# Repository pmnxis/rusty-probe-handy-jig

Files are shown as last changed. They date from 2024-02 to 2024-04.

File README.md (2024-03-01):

# The Rusty Probe

This is an open hardware probe for the Serial Wire Debug (SWD) and JTAG protocol.
Based on the RP2040 MCU.

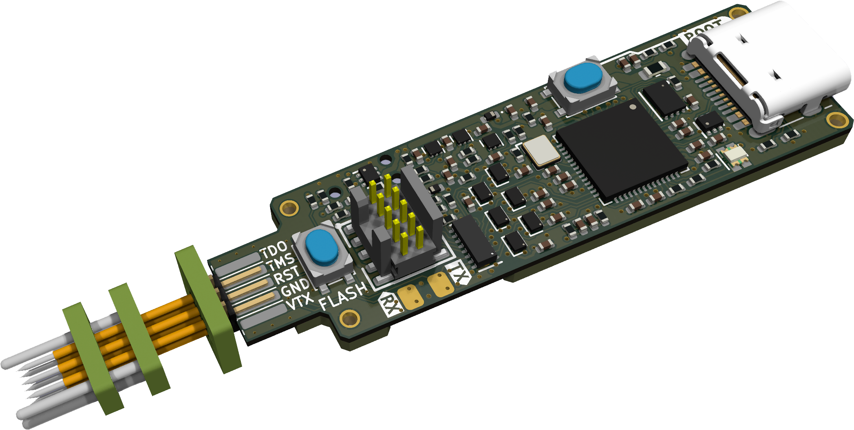
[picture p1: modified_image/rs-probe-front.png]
modified probe

Following image is forked and modified PCB 3D rendering.
This repo is modified PCB data details are descirbed in [here](#modification-on-this-forked-repo)

## Firmware

The firmware is available [here](https://github.com/probe-rs/rusty-probe-firmware) and is open-source.

## Features

- The 10-pin Cortex-Debug connector is used.
- The programming connector is the Tag Connect TC2030, however for just loading firmware the USB bootloader is recommended.
- Castellated vias for all programming pins, power and 2 GPIOs.
- USB-C connector.
- Target 5V and `Vtarget` is protected with an diode circuit to not have current flow from the target to the host.
- The probe support 1.8v - 3.3v signal voltage and can track `Vtarget`.
- The key pin on the Cortex-Debug can be connected to the protected 5V.

The schematic can be found in the GitHub actions, full production files are generated for each commit.

probe

## Comparison

Here is a small comparison with a few different probes:

| | Rusty Probe | PicoProbe | Raspberry Pi Debug Probe | STLinkV3 | JLink |
|---|---|---|---|---|---|
| Max speed | 62 MHz | ? | 10 MHz | 24 MHz | 15 MHz |
| Target support | any | any | any | STM32 | any |
| IO voltage control | 1.8-3.3V | 3.3V | 3.3V | 1.6-3.3V | 1.6-3.3V somtimes  |
| Type | Open Source & Hardware | Open Source | Proprietary | Proprietary | Proprietary |
| Language | Rust | C | C | C | C |
| Protocol | CMSIS-DAP | CMSIS-DAP | CMSIS-DAP | Proprietary | CMSIS-DAP |
| Programming connector | Cortex-M Debug 10p | - | JST | Cortex-M Debug 14p | Cortex-M Debug 10p |
| USB speed | 12 MBit/s | 12 MBit/s | 12 MBit/s | 480 MBit/s | 12 MBit/s |

## Where to buy

The original probe is available in the [probe-rs shop](https://shop.probe.rs/). But you are free to build one yourself as well!

## License

This work is licensed under [CERN-OHL-P](cern_ohl_p_v2.txt).

# Modification on this forked repo
modified probe
The existing rusty-probe has been modified for a practical experiment aiming to enable on-site, real-time firmware updates by individuals without programming knowledge. This modification incorporates BillMock-HW to facilitate firmware updates without the need for a computer.

## PCB Stack-Up
| | |
| --- | --- |
| Layer | 4 Layer |
| Material | FR4 |
| Impedence Control | Don't care (But choosed `JLC04081H-3313` ) |
| Thickness | **0.8 mm** |

In the modified board, a 1.27mm pin header is positioned at the left end to facilitate connection with a PogoProbe. The board is designed with a thickness of 0.8mm, considering the recommended thickness for the USB-C connector. While the original PCB uses 1.6mm thickness, using the USB-C connector directly (without PogoProbe) allows for the use of 1.6mm thickness as well.

By opting for the 0.8mm thickness, the durability of the PCB might be compromised. To address this, a BackPlane board is employed to reinforce and augment the insufficient rigidity.

| Front | Back |
| --- | --- |
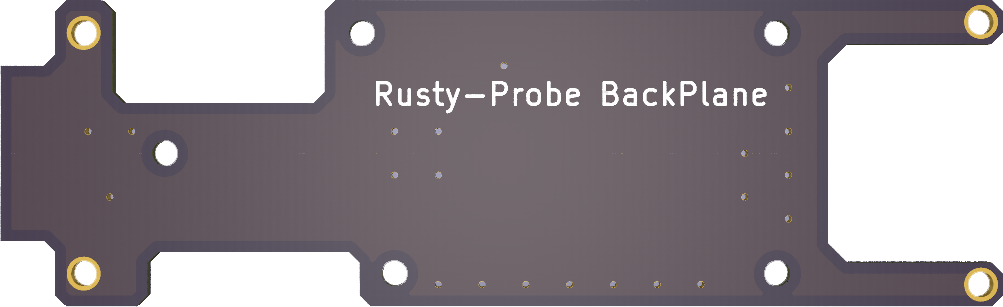
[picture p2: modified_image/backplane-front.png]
backplane-front
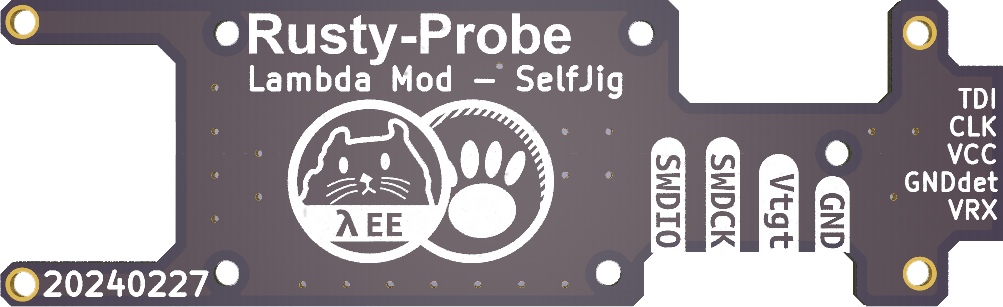
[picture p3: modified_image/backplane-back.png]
backplane-back
|  |  |
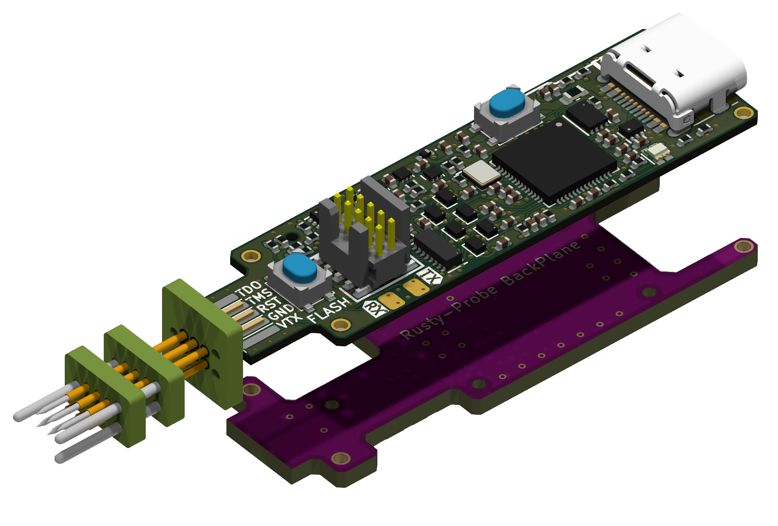
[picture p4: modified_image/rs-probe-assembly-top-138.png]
backplane-front-assembly-138mm
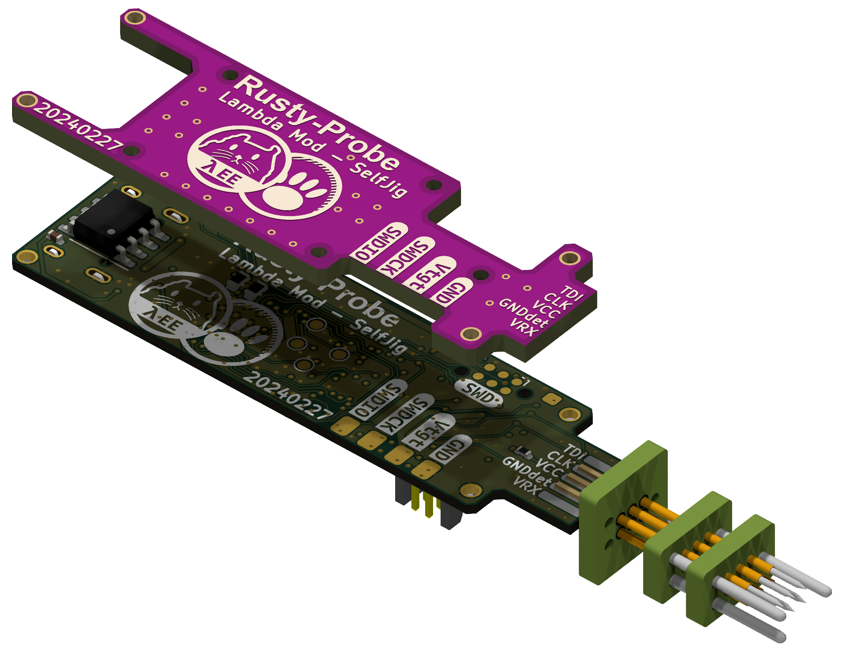
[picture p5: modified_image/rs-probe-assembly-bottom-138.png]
backplane-back-assembly-138mm
|  |  |
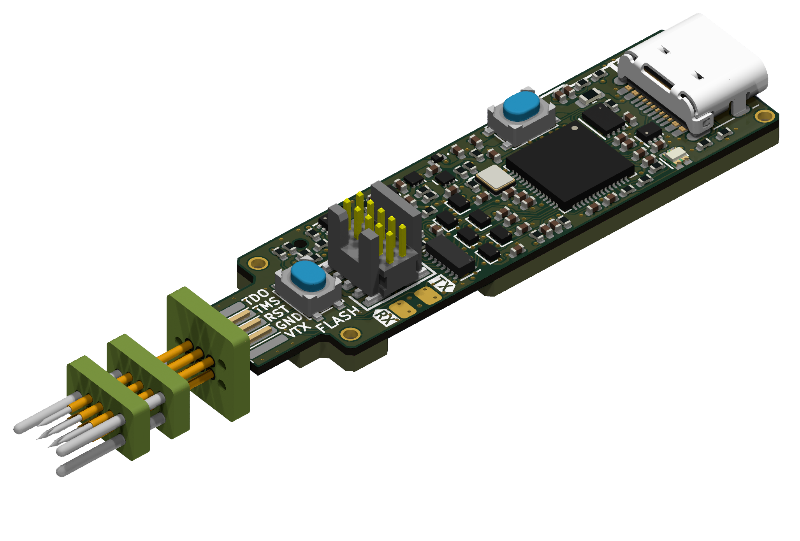
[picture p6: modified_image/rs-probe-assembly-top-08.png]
backplane-front-assembly-08mm
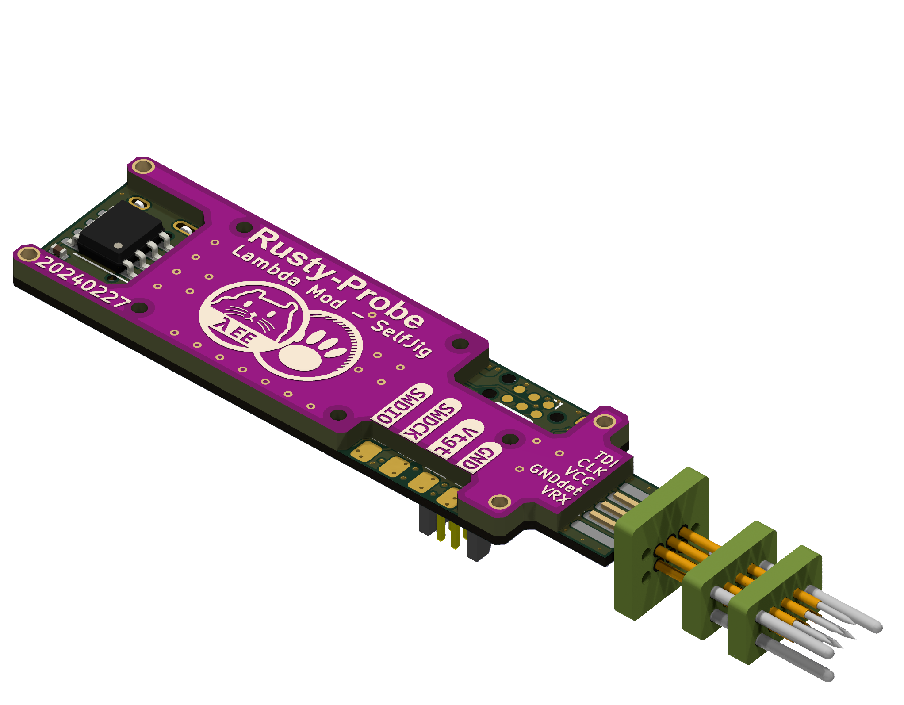
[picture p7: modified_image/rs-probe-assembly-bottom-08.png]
backplane-back-assembly-08mm
|  |  |
## Panelization 
JLCPCB's Panelization requires a minimum size of 70mm x 70mm when placing PCBs along the Edge Rail. To meet this requirement, I rotated the PCB by 90 degrees and arranged them in a 4x1 configuration. Additionally, I inserted a dummy bar in the middle for successful Panelization.

### Panlization by cli
```sh
# KiKit Required
cd ./panelize
./panelize_4batch.sh
```

## Changed Note
- Default `W25Q8` is replaced to `IS25WP016D` for custom code.
- Switch `EVQ-P2002W` is replaced to `TS-1145A-C-B` by personal ease of supply and demand of parts.
- Number of tact switch replaced to `TS-1145A-C-B` is changed to **2** from 1. Extra SW2 is connected to GPIO1. The plan of GPIO1 is using for USER input button (Ex Self Programming Button)
- Replace `74LVC1T45` to `X2-DFN1410-6` package and associated part.
- Castellated holes are removed for reducing the small scale unit production cost.
- The addition of a 5x2 SMD pad, designed to accommodate a 1.27mm pin header for vertical connection on the left side, has been made. This pad is intended for connecting a custom Pogo Pin (https://gitlab.com/michael1308/pogoprobe) and currently follows the pinout of the TC-2030 for consideration in the pin mapping of the personal project.
- Optionally added an I2C FRAM on the PCB bottom layer for data logging or frequent data storage purposes.
- Changed the selection of resistors and capacitors to those available in the JLCPCB Basic Part list.
- PCB width is increased to 49.9 mm from 40.0 mm
- Added and modified parameters to enable direct production with JLCPCB.
- Some libraries are referenced from [Lambda_KICAD_LIB](https://github.com/pmnxis/Lambda_KICAD_LIB)
kicad

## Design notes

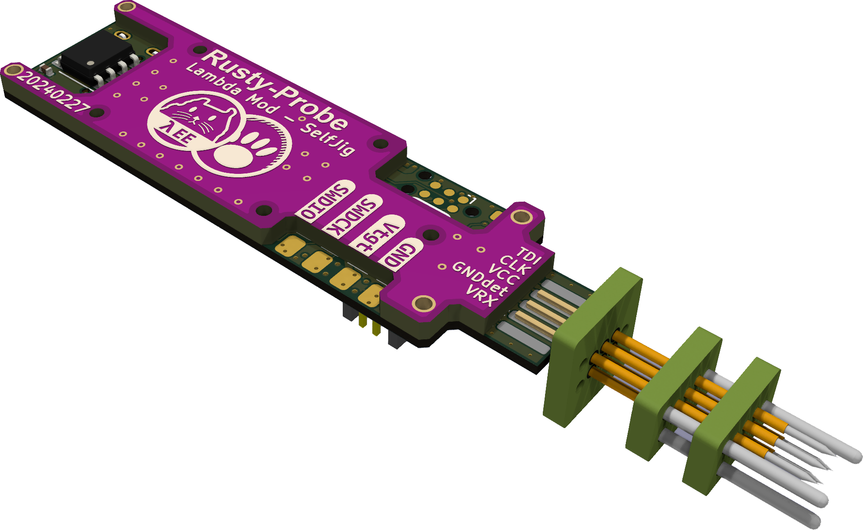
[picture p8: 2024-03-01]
modified_image/rs-probe-back.png

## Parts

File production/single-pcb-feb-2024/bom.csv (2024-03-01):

Designator | Footprint | Quantity | Value | LCSC Part #
C1, C10, C11, C12, C13, C14, C15, C16, C17, C18, C19, C20, C22, C23, C28, C31, C5, C7, C8, C9 | C_0402 | 20 | 0.1u | C307331
C2, C21, C24, C25, C26, C27, C29, C3, C30, C4, C6 | C_0402 | 11 | 2.2u | C170151
D1 | LED_LiteOn_LTST-C19HE1WT | 1 | LTST-C19HE1WT | C458749
D2, D3 | 0402 | 2 | 20V | C145312
F1 | 0603 | 1 | Fuse_Small | C210357
FB1 | R_0402 | 1 | BLM15AX601SN1D | C76886
J1 | USB_C_Receptacle_USB4105 | 1 | USB_C_Receptacle_USB2.0 | C167321
Q1 | SOT-563 | 1 | NTZD3155C | C895156
R1, R13, R15, R28 | R_0402 | 4 | 17.4k | C26957
R10, R18, R22, R23, R24, R26 | R_0402 | 6 | 1Meg | C138033
R11, R12, R14, R16, R19, R21, R27, R9 | R_0402 | 8 | 47k | C25792
R17, R2, R31, R5, R6, R7 | R_0402 | 6 | 1k | C11702
R20, R29, R3, R4, R8 | R_0402 | 5 | 5.1k | C25905
R25 | R_0402 | 1 | 15k | C25756
R30 | R_0402 | 1 | 0Ω | C17168
R32, R33 | R_0603 | 2 | 3.3kΩ 1608 | C22978
SW1, SW2 | SW_SPST_TS-1145A | 2 | TS-1145A-C-B | C465998
TH3, TH4 |  | 2 | Tooling Hole
U1, U10, U11, U2, U8, U9 | X2-DFN1410-6 | 6 | 74LVC1T45FZ4-7 | C150482
U12, U13, U14 | DFN-6-1EP_1.2x1.2mm_P0.4mm_EP0.3x0.94mm_PullBack | 3 | NCP133AMXADJTCG | C457672
U15 | SOIC-8_3.9x4.9mm_P1.27mm | 1 | FM24V02A-GTR | C382041
U3 | USON-8-3x2mm-EP | 1 | IS25WP016D-JULE-TR | C2976734
U4 | DFN-16-1EP_1.6x4mm_P0.5mm | 1 | NUF8401MNT4G | C895158
U5 | PinHeader_2x05_FTSH-105-01-L-DV-K | 1 | CortexDebug | C448647
U6 | RP2040-QFN-56 | 1 | RP2040 | C2040
U7 | SOT-563 | 1 | NUF2042XV6T1G | C90707
X1 | Crystal_SMD_2520-4Pin_2.5x2.0mm | 1 | 12 MHz | C255991

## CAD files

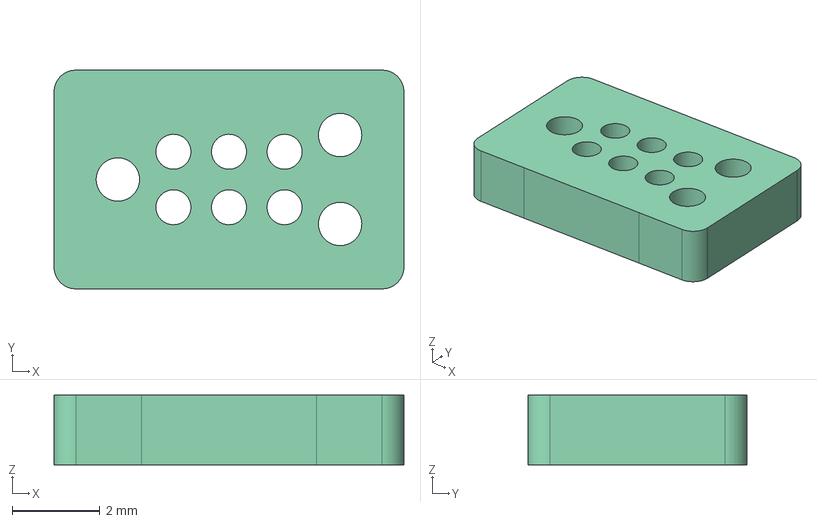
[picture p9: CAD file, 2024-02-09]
custom/TC2030-support.step
8.00 x 5.00 x 1.60 mm
Pcb_f6bc
topPads_f6bc
botPads_f6bc

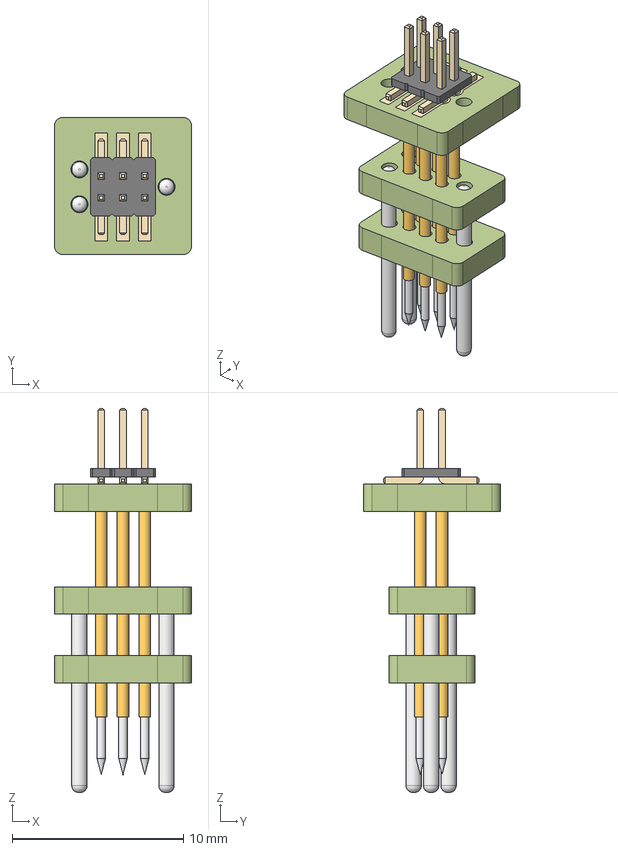
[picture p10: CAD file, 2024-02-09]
custom/PogoProbe-2030.step
8.00 x 8.00 x 22.4 mm
Pcb_ff3a
topPads_ff3a_cut
botPads_ff3a
REF_PinHeader_2x03_P127mm_Vertical_SMD_4153acf04981
REF_P50-E1_4153acf04981[2] x 6
REF_Body_0623b5cc9bbc x 3
REF_TC2030-support_e4265beada1b x 2

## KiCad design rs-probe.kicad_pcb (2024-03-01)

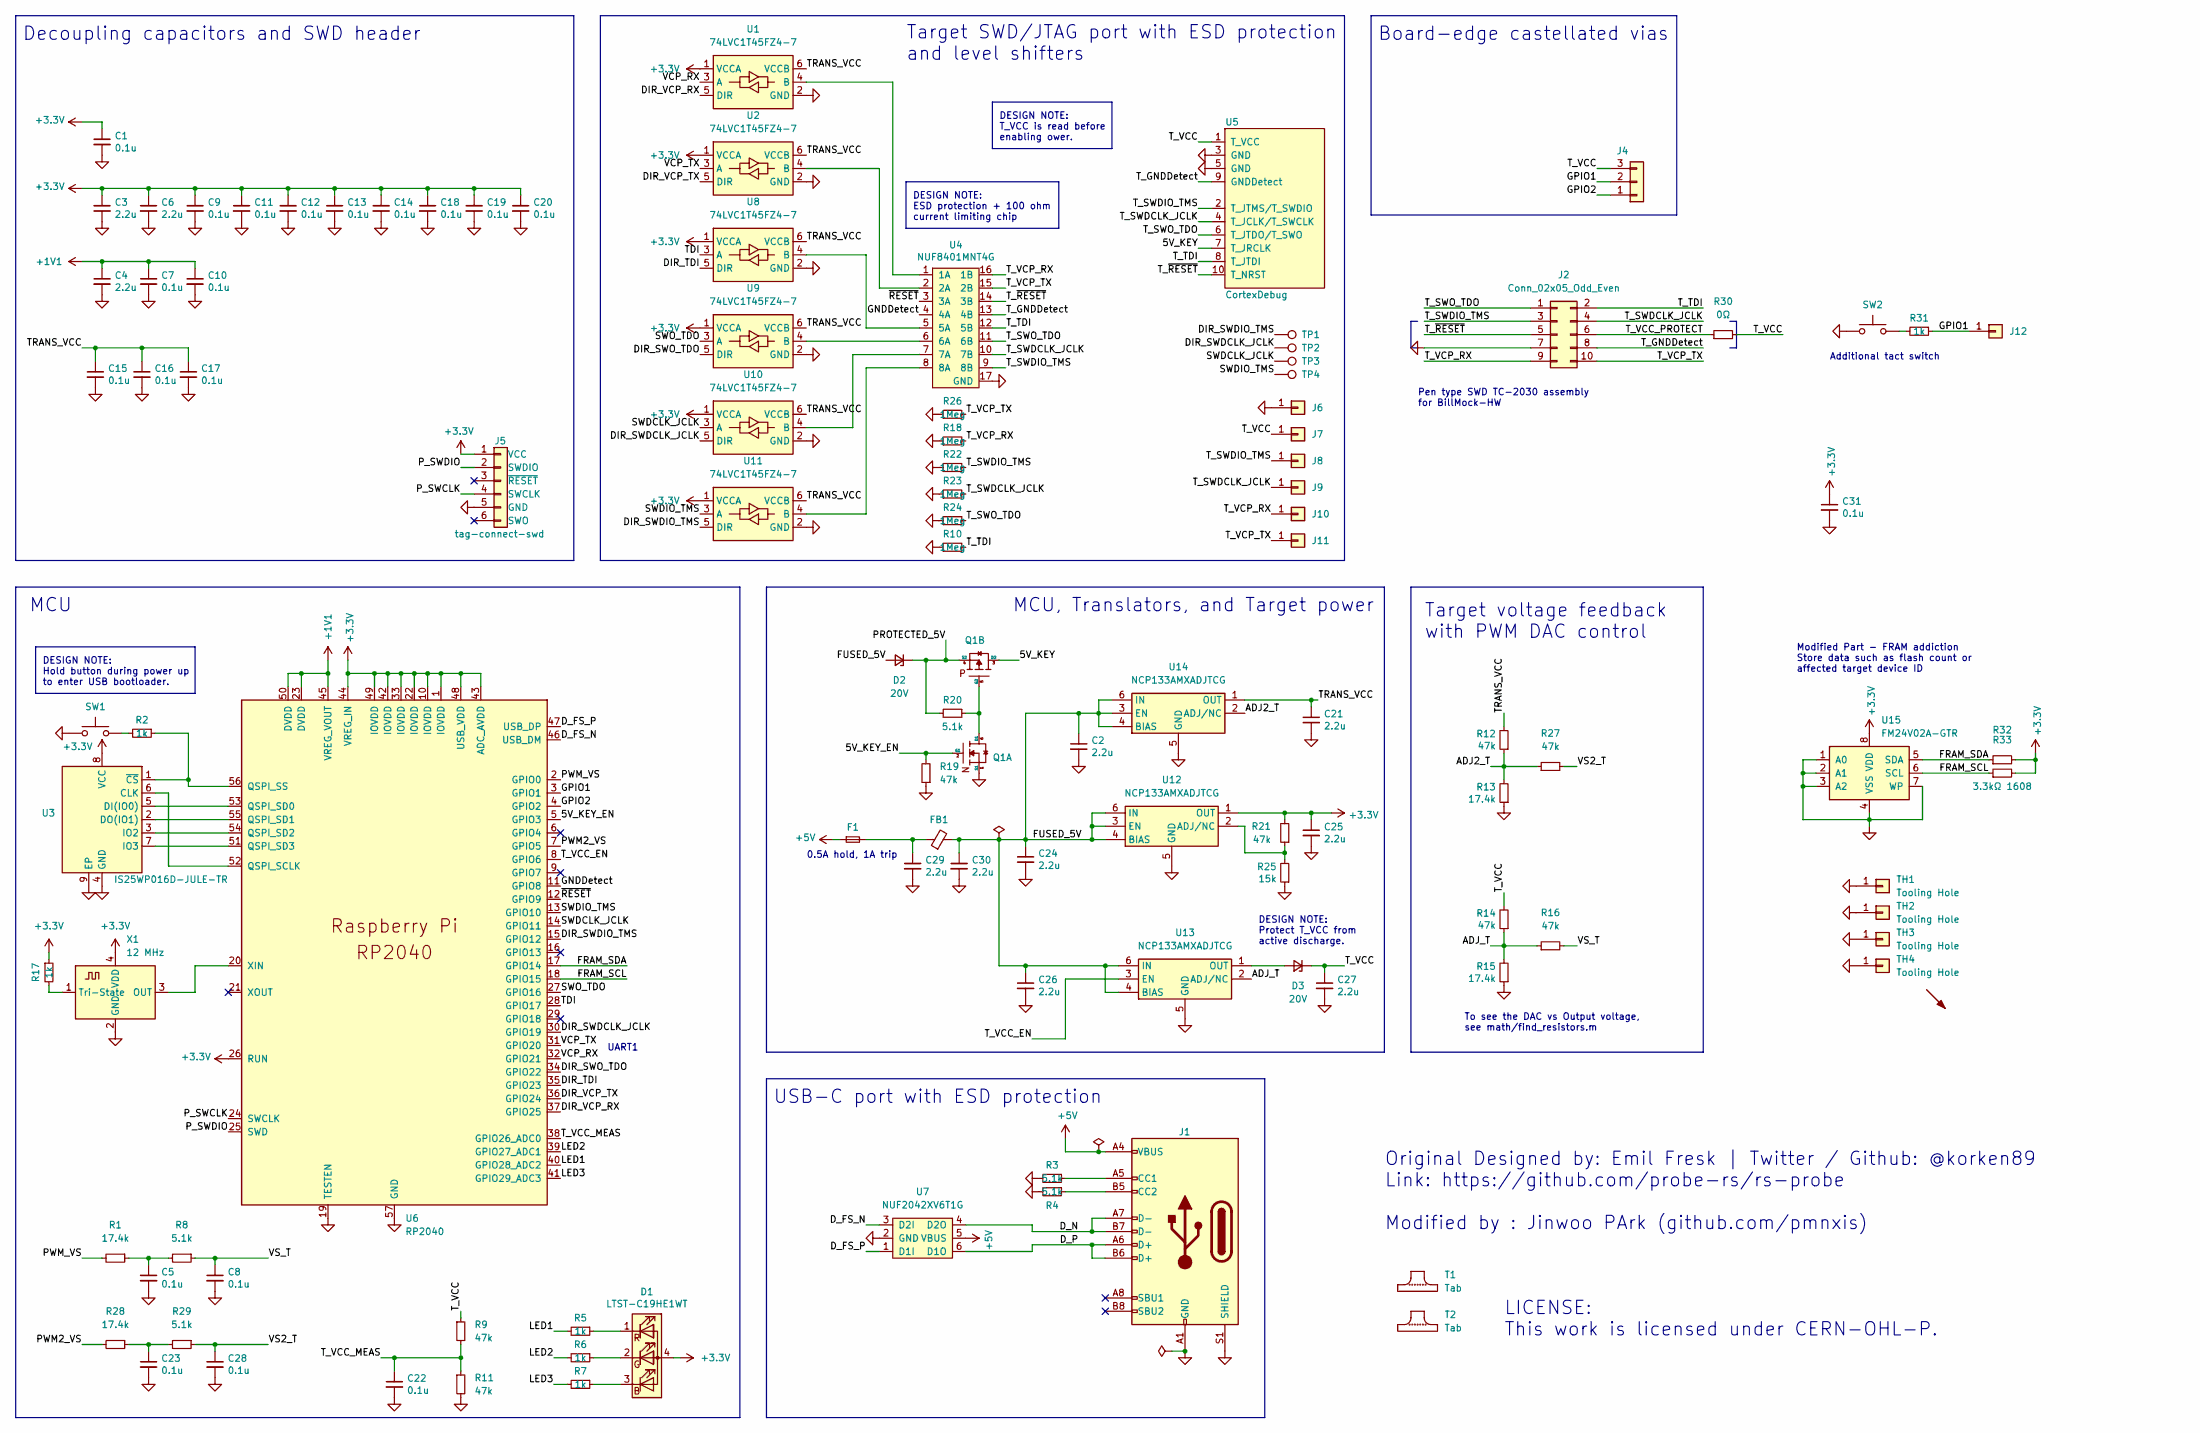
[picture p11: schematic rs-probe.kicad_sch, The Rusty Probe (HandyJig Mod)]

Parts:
C1, C5, C7, C8, C9, C10, C11, C12, C13, C14, C15, C16, C17, C18, C19, C20, C22, C23, C28, C31: 0.1u; C_0402; Tolerance 25V, X7R; LCSC C307331
C2, C3, C4, C6, C21, C24, C25, C26, C27, C29, C30: 2.2u; C_0402; Tolerance 10V, X5R; LCSC C170151
D1: LTST-C19HE1WT; LED_LiteOn_LTST-C19HE1WT; LCSC C458749
D2, D3: 20V; D_0402_1005Metric; LCSC C145312
F1: Fuse_Small; Fuse_0603_1608Metric; LCSC C210357
FB1: BLM15AX601SN1D; R_0402; LCSC C76886
J1: USB_C_Receptacle_USB2.0; USB_C_Receptacle_USB4105; LCSC C167321
J2: Conn_02x05_Odd_Even; TC2050-ProbeMod
J4: Castellated Vias; 1x3_1.5mm_castellated
J5: tag-connect-swd; Tag-Connect_TC2030-IDC-NL_2x03_P1.27mm_Vertical
J6, J7, J8, J9, J10, J11, J12: Conn_01x01; pad_1.5x2.0mm
Q1: NTZD3155C; SOT-563; LCSC C895156
R1, R13, R15, R28: 17.4k; R_0402; Tolerance 1%; LCSC C26957
R2, R5, R6, R7, R17, R31: 1k; R_0402; Tolerance 1%; LCSC C11702
R3, R4, R8, R20, R29: 5.1k; R_0402; Tolerance 1%; LCSC C25905
R9, R11, R12, R14, R16, R19, R21, R27: 47k; R_0402; Tolerance 1%; LCSC C25792
R10, R18, R22, R23, R24, R26: 1Meg; R_0402; Tolerance 1%; LCSC C138033
R25: 15k; R_0402; Tolerance 1%; LCSC C25756
R30: 0Ω; R_0402; Tolerance 1%; LCSC C17168
R32, R33: 3.3kΩ 1608; R_0603; Tolerance 1%; LCSC C22978
SW1, SW2: TS-1145A-C-B; SW_SPST_TS-1145A; LCSC C465998
SYM1: SYM_Arrow45_Normal; LamudaEE-12.3x7.6mm
T1, T2: Tab
TH1, TH2, TH3, TH4: Tooling Hole
TP1, TP2, TP3, TP4: TestPoint; TestPoint_Pad_D1.0mm
U1, U2, U8, U9, U10, U11: 74LVC1T45FZ4-7; X2-DFN1410-6; LCSC C150482
U3: IS25WP016D-JULE-TR; USON-8-3x2mm-EP; LCSC C2976734
U4: NUF8401MNT4G; DFN-16-1EP_1.6x4mm_P0.5mm; LCSC C895158
U5: CortexDebug; PinHeader_2x05_FTSH-105-01-L-DV-K; LCSC C448647
U6: RP2040; RP2040-QFN-56; LCSC C2040
U7: NUF2042XV6T1G; SOT-563; LCSC C90707
U12, U13, U14: NCP133AMXADJTCG; DFN-6-1EP_1.2x1.2mm_P0.4mm_EP0.3x0.94mm_PullBack; LCSC C457672
U15: FM24V02A-GTR; SOIC-8_3.9x4.9mm_P1.27mm; LCSC C382041
X1: 12 MHz; Crystal_SMD_2520-4Pin_2.5x2.0mm; LCSC C255991

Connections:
+1V1: C4.1, C7.1, C10.1, U6.23 (DVDD), U6.45 (VREG_VOUT), U6.50 (DVDD)
+3.3V: C1.1, C3.1, C6.1, C9.1, C11.1, C12.1, C13.1, C14.1, C18.1, C19.1, C20.1, C25.1, C31.1, D1.4 (A), J5.1 (VCC), R17.1, R21.2, R32.2, R33.2, U1.1 (VCCA), U2.1 (VCCA), U3.8 (VCC), U6.1 (IOVDD), U6.10 (IOVDD), U6.22 (IOVDD), U6.26 (RUN), U6.33 (IOVDD), U6.42 (IOVDD), U6.43 (ADC_AVDD), U6.44 (VREG_IN), U6.48 (USB_VDD), U6.49 (IOVDD), U8.1 (VCCA), U9.1 (VCCA), U10.1 (VCCA), U11.1 (VCCA), U12.1 (OUT), U15.8 (VDD), X1.4 (VDD)
+5V: F1.1, J1.A4 (VBUS), J1.A9 (VBUS), J1.B4 (VBUS), J1.B9 (VBUS), U7.5 (VBUS)
/5V_KEY: Q1.3 (D2), U5.7 (T_JRCLK)
/5V_KEY_EN: Q1.2 (G1), R19.2, U6.5 (GPIO3)
/ADJ2_T: R12.1, R13.2, R27.1, U14.2 (ADJ/NC)
/ADJ_T: R14.1, R15.2, R16.1, U13.2 (ADJ/NC)
/DIR_SWDCLK_JCLK: TP2.1, U6.30 (GPIO19), U10.5 (DIR)
/DIR_SWDIO_TMS: TP1.1, U6.15 (GPIO12), U11.5 (DIR)
/DIR_SWO_TDO: U6.34 (GPIO22), U9.5 (DIR)
/DIR_TDI: U6.35 (GPIO23), U8.5 (DIR)
/DIR_VCP_RX: U1.5 (DIR), U6.37 (GPIO25)
/DIR_VCP_TX: U2.5 (DIR), U6.36 (GPIO24)
/D_FS_N: U6.46 (USB_DM), U7.3 (D2I)
/D_FS_P: U6.47 (USB_DP), U7.1 (D1I)
/D_N: J1.A7 (D-), J1.B7 (D-), U7.4 (D2O)
/D_P: J1.A6 (D+), J1.B6 (D+), U7.6 (D1O)
/FRAM_SCL: R33.1, U6.18 (GPIO15), U15.6 (SCL)
/FRAM_SDA: R32.1, U6.17 (GPIO14), U15.5 (SDA)
/FUSED_5V: C2.1, C24.1, C26.1, C30.1, D2.2 (A), FB1.2, U12.3 (EN), U12.4 (BIAS), U12.6 (IN), U13.4 (BIAS), U13.6 (IN), U14.3 (EN), U14.4 (BIAS), U14.6 (IN)
/GNDDetect: U4.4 (4A), U6.11 (GPIO8)
/GPIO1: J4.2, J12.1, R31.1, U6.3 (GPIO1)
/GPIO2: J4.1, U6.4 (GPIO2)
/LED1: R5.2, U6.40 (GPIO28_ADC2)
/LED2: R6.2, U6.39 (GPIO27_ADC1)
/LED3: R7.2, U6.41 (GPIO29_ADC3)
/PROTECTED_5V: D2.1 (K), Q1.4 (S2), R20.2
/PWM2_VS: R28.2, U6.7 (GPIO5)
/PWM_VS: R1.2, U6.2 (GPIO0)
/P_SWCLK: J5.4 (SWCLK), U6.24 (SWCLK)
/P_SWDIO: J5.2 (SWDIO), U6.25 (SWD)
/SWDCLK_JCLK: TP3.1, U6.14 (GPIO11), U10.3 (A)
/SWDIO_TMS: TP4.1, U6.13 (GPIO10), U11.3 (A)
/SWO_TDO: U6.27 (GPIO16), U9.3 (A)
/TDI: U6.28 (GPIO17), U8.3 (A)
/TRANS_VCC: C15.1, C16.1, C17.1, C21.1, R12.2, U1.6 (VCCB), U2.6 (VCCB), U8.6 (VCCB), U9.6 (VCCB), U10.6 (VCCB), U11.6 (VCCB), U14.1 (OUT)
/T_GNDDetect: J2.8, U4.13 (4B), U5.9 (GNDDetect)
/T_SWDCLK_JCLK: J2.4, J9.1, R23.2, U4.10 (7B), U5.4 (T_JCLK/T_SWCLK)
/T_SWDIO_TMS: J2.3, J8.1, R22.2, U4.9 (8B), U5.2 (T_JTMS/T_SWDIO)
/T_SWO_TDO: J2.1, R24.2, U4.11 (6B), U5.6 (T_JTDO/T_SWO)
/T_TDI: J2.2, R10.2, U4.12 (5B), U5.8 (T_JTDI)
/T_VCC: C27.1, D3.1 (K), J4.3, J7.1, R9.1, R14.2, R30.2, U5.1 (T_VCC)
/T_VCC_EN: U6.8 (GPIO6), U13.3 (EN)
/T_VCC_MEAS: C22.1, R9.2, R11.1, U6.38 (GPIO26_ADC0)
/T_VCC_PROTECT: J2.6, R30.1
/T_VCP_RX: J2.9, J10.1, R18.2, U4.16 (1B)
/T_VCP_TX: J2.10, J11.1, R26.2, U4.15 (2B)
/T_~RESET: J2.5, U4.14 (3B), U5.10 (T_NRST)
/VCP_RX: U1.3 (A), U6.32 (GPIO21)
/VCP_TX: U2.3 (A), U6.31 (GPIO20)
/VS2_T: C28.1, R27.2, R29.1
/VS_T: C8.1, R8.1, R16.2
/~RESET: U4.3 (3A), U6.12 (GPIO9)
GND: C1.2, C2.2, C3.2, C4.2, C5.2, C6.2, C7.2, C8.2, C9.2, C10.2, C11.2, C12.2, C13.2, C14.2, C15.2, C16.2, C17.2, C18.2, C19.2, C20.2, C21.2, C22.2, C23.2, C24.2, C25.2, C26.2, C27.2, C28.2, C29.2, C30.2, C31.2, J1.A1 (GND), J1.A12 (GND), J1.B1 (GND), J1.B12 (GND), J1.S1 (SHIELD), J2.7, J5.5 (GND), J6.1, Q1.1 (S1), R3.2, R4.2, R10.1, R11.2, R13.1, R15.1, R18.1, R19.1, R22.1, R23.1, R24.1, R25.1, R26.1, SW1.1, SW2.1, TH1.1, TH2.1, TH3.1, TH4.1, U1.2 (GND), U2.2 (GND), U3.4 (GND), U3.9 (EP), U4.17 (GND), U5.3 (GND), U5.5 (GND), U6.19 (TESTEN), U6.57 (GND), U7.2 (GND), U8.2 (GND), U9.2 (GND), U10.2 (GND), U11.2 (GND), U12.5 (GND), U12.7 (GND), U13.5 (GND), U13.7 (GND), U14.5 (GND), U14.7 (GND), U15.1 (A0), U15.2 (A1), U15.3 (A2), U15.4 (VSS), U15.7 (WP), X1.2 (GND)
unnamed: C5.1, R1.1, R8.2
unnamed: C23.1, R28.1, R29.2
unnamed: C29.1, F1.2, FB1.1
unnamed: D1.3 (BK), R7.1
unnamed: D1.2 (GK), R6.1
unnamed: D1.1 (RK), R5.1
unnamed: D3.2 (A), U13.1 (OUT)
unnamed: J1.A5 (CC1), R3.1
unnamed: J1.B5 (CC2), R4.1
unnamed: Q1.5 (G2), Q1.6 (D1), R20.1
unnamed: R2.2, SW1.2
unnamed: R31.2, SW2.2
unnamed: U1.4 (B), U4.1 (1A)
unnamed: U2.4 (B), U4.2 (2A)
unnamed: U3.6 (CLK), U6.52 (QSPI_SCLK)
unnamed: U3.5 (DI(IO0)), U6.53 (QSPI_SD0)
unnamed: U3.2 (DO(IO1)), U6.55 (QSPI_SD1)
unnamed: U3.3 (IO2), U6.54 (QSPI_SD2)
unnamed: U3.7 (IO3), U6.51 (QSPI_SD3)
unnamed: R2.1, U3.1 (~CS), U6.56 (QSPI_SS)
unnamed: U4.5 (5A), U8.4 (B)
unnamed: U4.6 (6A), U9.4 (B)
unnamed: U6.20 (XIN), X1.3 (OUT)
unnamed: U4.7 (7A), U10.4 (B)
unnamed: U4.8 (8A), U11.4 (B)
unnamed: R21.1, R25.2, U12.2 (ADJ/NC)
unnamed: R17.2, X1.1 (Tri-State)

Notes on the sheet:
Target SWD/JTAG port with ESD protection and level shifters
Target voltage feedback with PWM DAC control
To see the DAC vs Output voltage, see math/find_resistors.m
USB-C port with ESD protection
DESIGN NOTE: T_VCC is read before enabling ower.
Original Designed by: Emil Fresk | Twitter / Github: @korken89 Link: https://github.com/probe-rs/rs-probe Modified by : Jinwoo PArk (github.com/pmnxis)
Modified Part - FRAM addiction Store data such as flash count or affected target device ID
Board-edge castellated vias
DESIGN NOTE: ESD protection + 100 ohm current limiting chip
Pen type SWD TC-2030 assembly for BillMock-HW
Decoupling capacitors and SWD header
MCU
0.5A hold, 1A trip
MCU, Translators, and Target power
DESIGN NOTE: Protect T_VCC from active discharge.
Additional tact switch
DESIGN NOTE: Hold button during power up to enter USB bootloader.
UART1
LICENSE: This work is licensed under CERN-OHL-P.

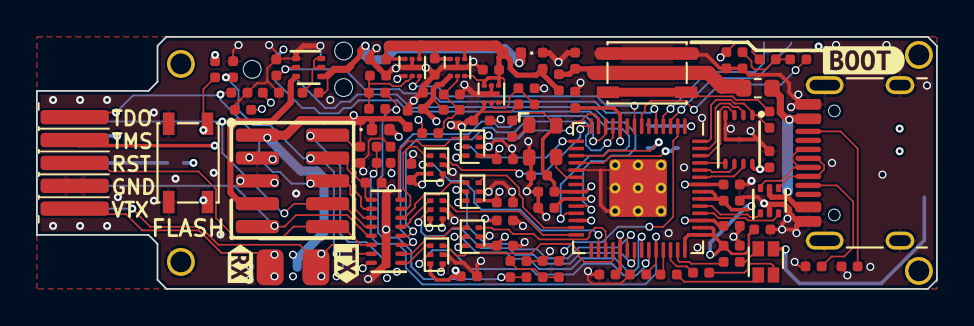
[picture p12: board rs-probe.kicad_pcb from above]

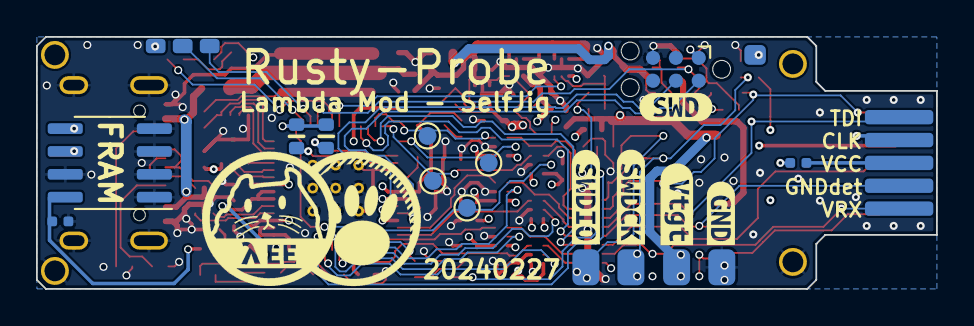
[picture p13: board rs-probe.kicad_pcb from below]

Board: 4 copper layers, 50.0 x 14.0 mm, 120 parts (22 on the bottom side), 81 nets.

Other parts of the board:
T1#2, T2#2: Tab
kibuzzard-61EE8014: G***; kibuzzard-61EE8014
kibuzzard-61FE7ECB: G***; kibuzzard-61FE7ECB
kibuzzard-61FE80B0: G***; kibuzzard-61FE80B0
kibuzzard-61FE80BD: G***; kibuzzard-61FE80BD
kibuzzard-61FE8065: G***; kibuzzard-61FE8065
kibuzzard-61FE8092: G***; kibuzzard-61FE8092
kibuzzard-6228D4B3: G***; kibuzzard-6228D4B3
kibuzzard-6228D4CF: G***; kibuzzard-6228D4CF

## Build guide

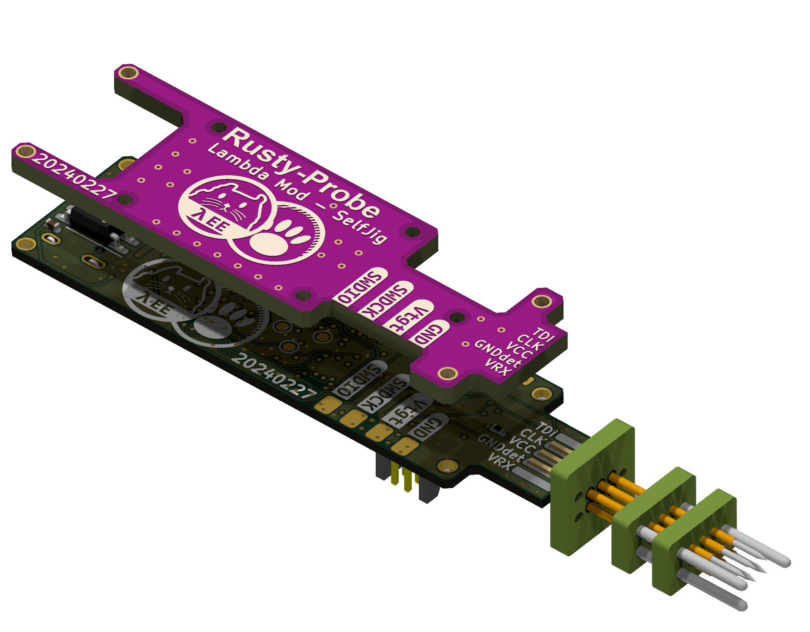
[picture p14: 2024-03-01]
modified_image/rs-probe-assembly-bottom-83.png

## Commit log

2024-02-09 Modification for BillMock-HW on-site programming
    [PogoProbe-2030.step, TC2030-support.step, bom.csv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]
2024-03-01 Fabricated on JLCPCB (not tested yet)
    [backplane.kicad_pcb, bom.csv, designators.csv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]
2024-03-01 Add assembly image
2024-04-08 final production file
    [backplane.kicad_pcb]
